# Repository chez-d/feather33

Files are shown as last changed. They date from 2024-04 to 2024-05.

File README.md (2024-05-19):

# feather33
Feather form-factor board with a 1.4GHz quad-core A33 from Allwinner.

For assembly, any <=512MB DDR3L should* work (no MCP). 

A 50p board-to-board connector is added to break out another USB, audio, and parallel RGB among other things

This board is designed to work with OSHPark's 6L service and to be assembled with a stencil and hotplate/hot air.

## Initial Testing
Assembled board works fine and communicates over USB.
2 IMPORTANT THINGS!!!
- You cannot boot from MMC1, sadly I discovered this *after* I got the boards. You'll have to first boot off of a SPI flash then use that to jump onto MMC1.
- DDR is still not confirmed.

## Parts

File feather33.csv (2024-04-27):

# | Reference | Qty | Value | Footprint | DNP
1 | C1, C3, C8, C9, C10, C11, C16, C21, C22, C31, C40, C49, C56, C57 | 14 | 1u | Capacitor_SMD:C_0402_1005Metric
2 | C2, C17, C20, C24, C25, C29, C30, C32, C33, C34, C35, C37, C42, C45, C46, C47, C50, C51, C52, C55, C60, C61, C62, C63, C64, C66, C67, C68, C69, C70 | 30 | 100n | Capacitor_SMD:C_0402_1005Metric
3 | C4, C5, C6, C7, C18, C19, C48, C65, C71 | 9 | 22u | Capacitor_SMD:C_0805_2012Metric
4 | C12, C13, C14, C15, C23, C28, C36, C41, C43, C44 | 10 | 10u | Capacitor_SMD:C_0603_1608Metric
5 | C26, C27, C38, C39 | 4 | TBD | Capacitor_SMD:C_0402_1005Metric
6 | CN1 | 1 | YXT-BB10-50P-02 | parts:CONN-SMD_YXT-BB10-50P-02
7 | D1 | 1 | STAT | LED_SMD:LED_0603_1608Metric
8 | D2, D3 | 2 | D_Schottky | Diode_SMD:D_SOD-323
9 | D4 | 1 | PWR | LED_SMD:LED_0603_1608Metric
10 | J1 | 1 | Micro_SD_Card_Det2 | Connector_Card:microSD_HC_Molex_104031-0811
11 | J2 | 1 | USB_C_Receptacle_USB2.0 | parts:USB-C_SMD-TYPE-C-31-M-12
12 | J3 | 1 | BATT | parts:CONN-SMD_X2016WRS-02-9TSW
13 | J4 | 1 | qwiic | Connector_JST:JST_SH_BM04B-SRSS-TB_1x04-1MP_P1.00mm_Vertical
14 | J5 | 1 | Conn_01x16 | parts:PinHeader_1x16_P2.54mm_Feather
15 | J6 | 1 | Conn_01x12 | parts:PinHeader_1x12_P2.54mm_Feather
16 | L1, L2, L3 | 3 | 1uH | parts:IND-SMD_L2.5-W2.0-VLS252012CX-150M
17 | R1 | 1 | 1k | Resistor_SMD:R_0402_1005Metric
18 | R2, R14, R19, R23, R24, R33 | 6 | 2k | Resistor_SMD:R_0402_1005Metric
19 | R3 | 1 | 124k | Resistor_SMD:R_0402_1005Metric
20 | R4, R12, R16 | 3 | 100k | Resistor_SMD:R_0402_1005Metric
21 | R5, R10, R13 | 3 | 10k | Resistor_SMD:R_0402_1005Metric
22 | R6, R15 | 2 | 68k | Resistor_SMD:R_0402_1005Metric
23 | R7 | 1 | 82k | Resistor_SMD:R_0402_1005Metric
24 | R8 | 1 | 510k | Resistor_SMD:R_0402_1005Metric
25 | R9 | 1 | 110k | Resistor_SMD:R_0402_1005Metric
26 | R11 | 1 | 316k | Resistor_SMD:R_0402_1005Metric
27 | R17, R18, R20, R21 | 4 | 5.1k | Resistor_SMD:R_0402_1005Metric
28 | R22 | 1 | 200k | Resistor_SMD:R_0402_1005Metric
29 | R25, R26 | 2 | 22 | Resistor_SMD:R_0402_1005Metric
30 | R27, R31 | 2 | 240 | Resistor_SMD:R_0402_1005Metric
31 | SW1 | 1 | SW_Push | Button_Switch_SMD:SW_SPST_PTS810
32 | U1 | 1 | BQ24040DSQR | parts:WSON-10_L2.0-W2.0-P0.40-BL-EP
33 | U2 | 1 | ~ | Package_DFN_QFN:VQFN-24-1EP_4x4mm_P0.5mm_EP2.5x2.5mm
34 | U3 | 1 | A33 | parts:BGA-282_L14.0-W14.0-R17-W17-P0.8-TL
35 | U5 | 1 | K4B4G1646E-BYMA 4GB | parts:FBGA-96_L13.5-W7.5-R16-C6-P0.80-TL
36 | U6 | 1 | NEOPIXEL | parts:LED-SMD_4P-L1.6-W1.5_XL-1615RGBC-WS2812B
37 | Y1 | 1 | 32768 | Crystal:Crystal_SMD_3215-2Pin_3.2x1.5mm
38 | Y2 | 1 | 24M | Crystal:Crystal_SMD_2016-4Pin_2.0x1.6mm

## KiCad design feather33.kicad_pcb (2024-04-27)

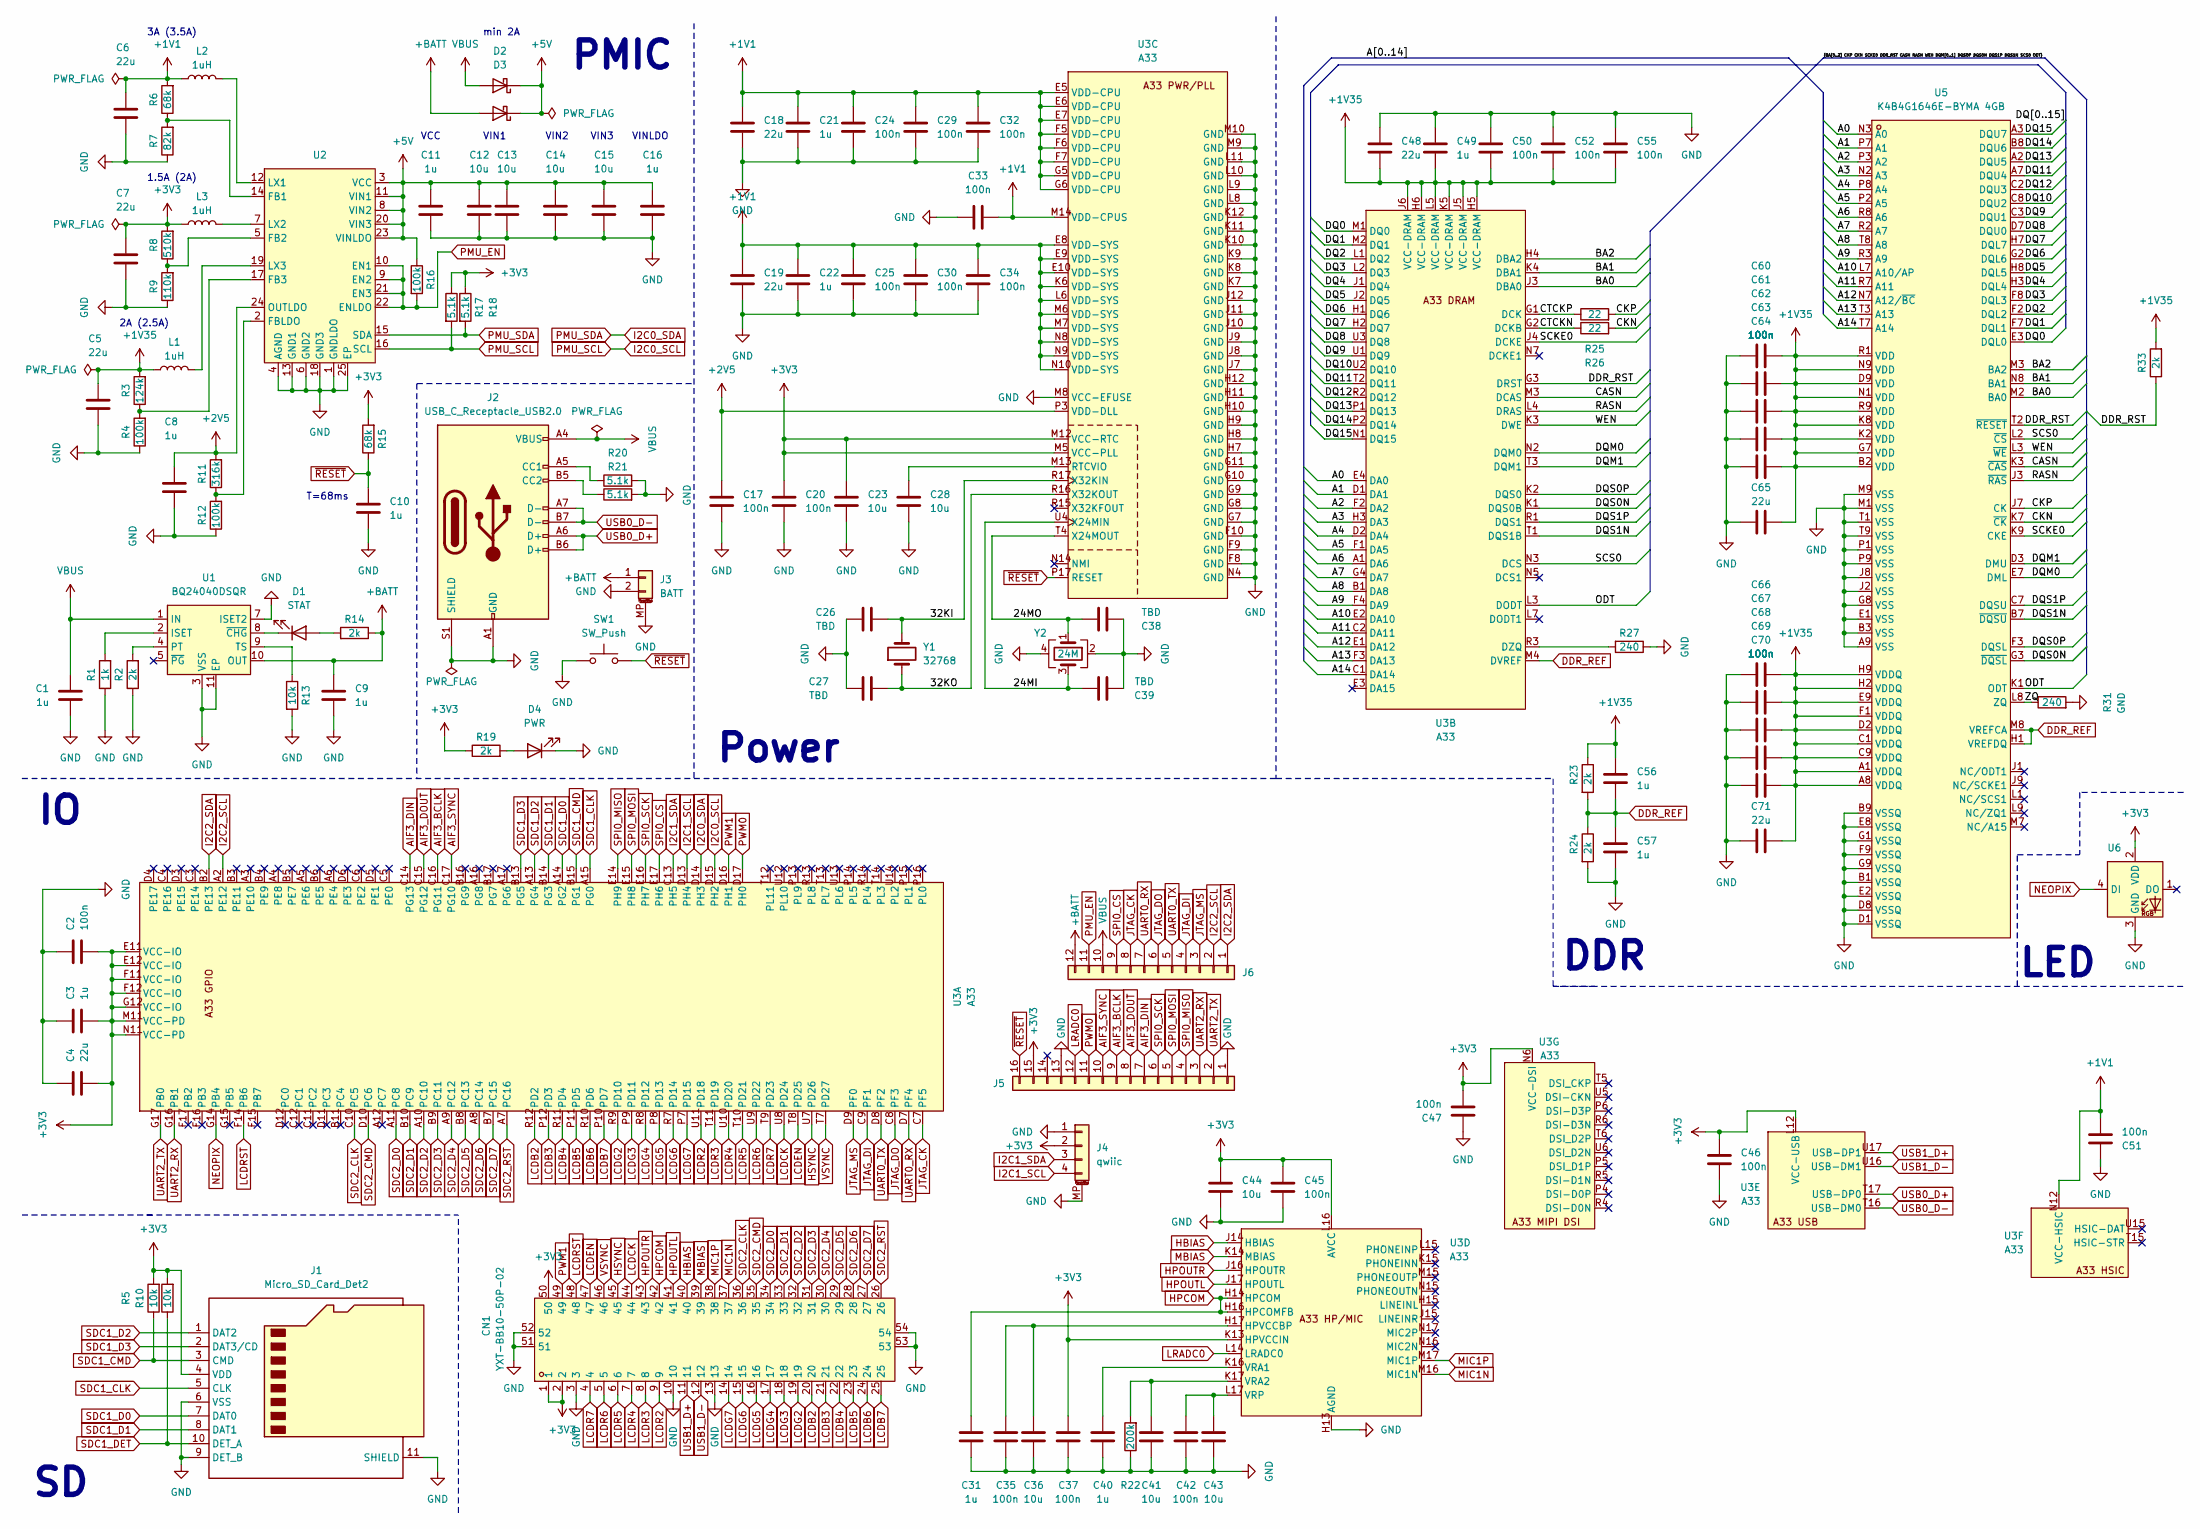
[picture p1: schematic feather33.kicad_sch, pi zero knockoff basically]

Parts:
C1, C3, C8, C9, C10, C11, C16, C21, C22, C31, C40, C49, C56, C57: 1u; C_0402_1005Metric
C2, C17, C20, C24, C25, C29, C30, C32, C33, C34, C35, C37, C42, C45, C46, C47, C50, C51, C52, C55, C60, C61, C62, C63, C64, C66, C67, C68, C69, C70: 100n; C_0402_1005Metric
C4, C5, C6, C7, C18, C19, C48, C65, C71: 22u; C_0805_2012Metric
C12, C13, C14, C15, C23, C28, C36, C41, C43, C44: 10u; C_0603_1608Metric
C26, C27, C38, C39: TBD; C_0402_1005Metric
CN1: YXT-BB10-50P-02; CONN-SMD_YXT-BB10-50P-02; LCSC Part C2763977
D1: STAT; LED_0603_1608Metric
D2, D3: D_Schottky; D_SOD-323
D4: PWR; LED_0603_1608Metric
J1: Micro_SD_Card_Det2; microSD_HC_Molex_104031-0811
J2: USB_C_Receptacle_USB2.0; USB-C_SMD-TYPE-C-31-M-12
J3: BATT; CONN-SMD_X2016WRS-02-9TSW
J4: qwiic; JST_SH_BM04B-SRSS-TB_1x04-1MP_P1.00mm_Vertical
J5: Conn_01x16; PinHeader_1x16_P2.54mm_Feather
J6: Conn_01x12; PinHeader_1x12_P2.54mm_Feather
L1, L2, L3: 1uH; IND-SMD_L2.5-W2.0-VLS252012CX-150M
R1: 1k; R_0402_1005Metric
R2, R14, R19, R23, R24, R33: 2k; R_0402_1005Metric
R3: 124k; R_0402_1005Metric
R4, R12, R16: 100k; R_0402_1005Metric
R5, R10, R13: 10k; R_0402_1005Metric
R6, R15: 68k; R_0402_1005Metric
R7: 82k; R_0402_1005Metric
R8: 510k; R_0402_1005Metric
R9: 110k; R_0402_1005Metric
R11: 316k; R_0402_1005Metric
R17, R18, R20, R21: 5.1k; R_0402_1005Metric
R22: 200k; R_0402_1005Metric
R25, R26: 22; R_0402_1005Metric
R27, R31: 240; R_0402_1005Metric
SW1: SW_Push; SW_SPST_PTS810
U1: BQ24040DSQR; WSON-10_L2.0-W2.0-P0.40-BL-EP; LCSC Part C81080
U2: VQFN-24-1EP_4x4mm_P0.5mm_EP2.5x2.5mm
U3: A33; BGA-282_L14.0-W14.0-R17-W17-P0.8-TL
U5: K4B4G1646E-BYMA 4GB; FBGA-96_L13.5-W7.5-R16-C6-P0.80-TL; LCSC Part C500275
U6: NEOPIXEL; LED-SMD_4P-L1.6-W1.5_XL-1615RGBC-WS2812B; LCSC Part C5349954
Y1: 32768; Crystal_SMD_3215-2Pin_3.2x1.5mm
Y2: 24M; Crystal_SMD_2016-4Pin_2.0x1.6mm

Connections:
+1V1: C6.1, C18.1, C19.1, C21.1, C22.1, C24.1, C25.1, C29.1, C30.1, C32.1, C33.2, C34.1, C51.2, L2.1, R6.2, U3.E5 (VDD-CPU), U3.E6 (VDD-CPU), U3.E7 (VDD-CPU), U3.E8 (VDD-SYS), U3.E9 (VDD-SYS), U3.E10 (VDD-SYS), U3.F5 (VDD-CPU), U3.F6 (VDD-CPU), U3.F7 (VDD-CPU), U3.G5 (VDD-CPU), U3.G6 (VDD-CPU), U3.K6 (VDD-SYS), U3.L6 (VDD-SYS), U3.M6 (VDD-SYS), U3.M7 (VDD-SYS), U3.M14 (VDD-CPUS), U3.N8 (VDD-SYS), U3.N9 (VDD-SYS), U3.N10 (VDD-SYS), U3.N12 (VCC-HSIC)
+1V35: C5.1, C48.2, C49.2, C50.2, C52.2, C55.2, C56.1, C60.2, C61.2, C62.2, C63.2, C64.2, C65.2, C66.2, C67.2, C68.2, C69.2, C70.2, C71.2, L1.1, R3.2, R23.1, R33.2, U3.H5 (VCC-DRAM), U3.H6 (VCC-DRAM), U3.J5 (VCC-DRAM), U3.J6 (VCC-DRAM), U3.K5 (VCC-DRAM), U3.L5 (VCC-DRAM), U5.A1 (VDDQ), U5.A8 (VDDQ), U5.B2 (VDD), U5.C1 (VDDQ), U5.C9 (VDDQ), U5.D2 (VDDQ), U5.D9 (VDD), U5.E9 (VDDQ), U5.F1 (VDDQ), U5.G7 (VDD), U5.H2 (VDDQ), U5.H9 (VDDQ), U5.K2 (VDD), U5.K8 (VDD), U5.N1 (VDD), U5.N9 (VDD), U5.R1 (VDD), U5.R9 (VDD)
+2V5: C8.1, C17.1, R11.2, U2.24 (OUTLDO), U3.P3 (VDD-DLL)
+3V3: C2.2, C3.2, C4.2, C7.1, C20.1, C23.1, C37.1, C44.1, C45.1, C46.1, C47.2, CN1.1, CN1.2, CN1.50, J1.4 (VDD), J4.2, J5.15, L3.1, R5.2, R8.2, R10.2, R15.2, R17.1, R18.1, R19.1, U3.E11 (VCC-IO), U3.E12 (VCC-IO), U3.F11 (VCC-IO), U3.F12 (VCC-IO), U3.G12 (VCC-IO), U3.K13 (HPVCCIN), U3.L12 (VCC-USB), U3.L16 (AVCC), U3.M5 (VCC-PLL), U3.M11 (VCC-PD), U3.M12 (VCC-RTC), U3.N6 (VCC-DSI), U3.N11 (VCC-PD), U6.2 (VDD)
+5V: C11.1, C12.1, C13.1, C14.1, C15.1, C16.1, D2.1 (K), D3.1 (K), R16.1, U2.3 (VCC), U2.8 (VIN2), U2.11 (VIN1), U2.20 (VIN3), U2.23 (VINLDO)
+BATT: C9.1, D3.2 (A), J3.1, J6.12, R14.1, U1.10 (OUT)
/24MI: C39.2, U3.U4 (X24MIN), Y2.3
/24MO: C38.2, U3.T4 (X24MOUT), Y2.1
/32KI: C26.2, U3.R17 (X32KIN), Y1.2
/32KO: C27.2, U3.R16 (X32KOUT), Y1.1
/A0: U3.E4 (DA0), U5.N3 (A0)
/A1: U3.D1 (DA1), U5.P7 (A1)
/A2: U3.F2 (DA2), U5.P3 (A2)
/A3: U3.H3 (DA3), U5.N2 (A3)
/A4: U3.D2 (DA4), U5.P8 (A4)
/A5: U3.F1 (DA5), U5.P2 (A5)
/A6: U3.A1 (DA6), U5.R8 (A6)
/A7: U3.G4 (DA7), U5.R2 (A7)
/A8: U3.B1 (DA8), U5.T8 (A8)
/A9: U3.F4 (DA9), U5.R3 (A9)
/A10: U3.E2 (DA10), U5.L7 (A10/AP)
/A11: U3.C2 (DA11), U5.R7 (A11)
/A12: U3.E1 (DA12), U5.N7 (A12/~BC)
/A13: U3.F3 (DA13), U5.T3 (A13)
/A14: U3.C1 (DA14), U5.T7 (A14)
/BA0: U3.J3 (DBA0), U5.M2 (BA0)
/BA1: U3.K4 (DBA1), U5.N8 (BA1)
/BA2: U3.H4 (DBA2), U5.M3 (BA2)
/CASN: U3.M3 (DCAS), U5.K3 (~CAS)
/CKN: R26.2, U5.K7 (~CK)
/CKP: R25.2, U5.J7 (CK)
/CTCKN: R26.1, U3.G2 (DCKB)
/CTCKP: R25.1, U3.G1 (DCK)
/DDR_RST: R33.1, U3.G3 (DRST), U5.T2 (~RESET)
/DQ0: U3.M1 (DQ0), U5.E3 (DQL0)
/DQ1: U3.M2 (DQ1), U5.F7 (DQL1)
/DQ2: U3.L1 (DQ2), U5.F2 (DQL2)
/DQ3: U3.L2 (DQ3), U5.F8 (DQL3)
/DQ4: U3.J1 (DQ4), U5.H3 (DQL4)
/DQ5: U3.J2 (DQ5), U5.H8 (DQL5)
/DQ6: U3.H1 (DQ6), U5.G2 (DQL6)
/DQ7: U3.H2 (DQ7), U5.H7 (DQL7)
/DQ8: U3.U3 (DQ8), U5.D7 (DQU0)
/DQ9: U3.U1 (DQ9), U5.C3 (DQU1)
/DQ10: U3.U2 (DQ10), U5.C8 (DQU2)
/DQ11: U3.T2 (DQ11), U5.A7 (DQU4)
/DQ12: U3.R2 (DQ12), U5.C2 (DQU3)
/DQ13: U3.P1 (DQ13), U5.A2 (DQU5)
/DQ14: U3.P2 (DQ14), U5.B8 (DQU6)
/DQ15: U3.N1 (DQ15), U5.A3 (DQU7)
/DQM0: U3.N2 (DQM0), U5.E7 (DML)
/DQM1: U3.T3 (DQM1), U5.D3 (DMU)
/DQS0N: U3.K1 (DQS0B), U5.G3 (~DQSL)
/DQS0P: U3.K2 (DQS0), U5.F3 (DQSL)
/DQS1N: U3.T1 (DQS1B), U5.B7 (~DQSU)
/DQS1P: U3.R1 (DQS1), U5.C7 (DQSU)
/ODT: U3.L3 (DODT), U5.K1 (ODT)
/RASN: U3.L4 (DRAS), U5.J3 (~RAS)
/SCKE0: U3.J4 (DCKE), U5.K9 (CKE)
/SCS0: U3.N3 (DCS), U5.L2 (~CS)
/WEN: U3.K3 (DWE), U5.L3 (~WE)
/ZQ: R31.1, U5.L8 (ZQ)
AIF3_BCLK: J5.9, U3.C16 (PG11)
AIF3_DIN: J5.7, U3.C14 (PG13)
AIF3_DOUT: J5.8, U3.C15 (PG12)
AIF3_SYNC: J5.10, U3.C17 (PG10)
DDR_REF: C56.2, C57.1, R23.2, R24.1, U3.M4 (DVREF), U5.H1 (VREFDQ), U5.M8 (VREFCA)
GND: C1.2, C2.1, C3.1, C4.1, C5.2, C6.2, C7.2, C8.2, C9.2, C10.2, C11.2, C12.2, C13.2, C14.2, C15.2, C16.2, C17.2, C18.2, C19.2, C20.2, C21.2, C22.2, C23.2, C24.2, C25.2, C26.1, C27.1, C28.2, C29.2, C30.2, C31.2, C32.2, C33.1, C34.2, C35.2, C36.2, C37.2, C38.1, C39.1, C40.2, C41.2, C42.2, C43.2, C44.2, C45.2, C46.2, C47.1, C48.1, C49.1, C50.1, C51.1, C52.1, C55.1, C57.2, C60.1, C61.1, C62.1, C63.1, C64.1, C65.1, C66.1, C67.1, C68.1, C69.1, C70.1, C71.1, CN1.3, CN1.10, CN1.13, CN1.51, CN1.52, CN1.53, CN1.54, D4.1 (K), J1.6 (VSS), J1.9 (DET_B), J1.11 (SHIELD), J2.A1 (GND), J2.A12 (GND), J2.B1 (GND), J2.B12 (GND), J2.S1 (SHIELD), J3.2, J3.MP (MountPin), J4.1, J4.MP (MountPin), J5.1, J5.13, R1.1, R2.1, R4.1, R7.1, R9.1, R12.1, R13.2, R20.2, R21.2, R22.1, R24.2, R27.1, R31.2, SW1.1, U1.3 (VSS), U1.7 (ISET2), U1.11 (EP), U2.1 (GNDLDO), U2.4 (AGND), U2.6 (GND2), U2.13 (GND1), U2.18 (GND3), U2.25 (EP), U3.F8 (GND), U3.F9 (GND), U3.F10 (GND), U3.G7 (GND), U3.G8 (GND), U3.G9 (GND), U3.G10 (GND), U3.G11 (GND), U3.H7 (GND), U3.H8 (GND), U3.H9 (GND), U3.H10 (GND), U3.H11 (GND), U3.H12 (GND), U3.H13 (AGND), U3.J7 (GND), U3.J8 (GND), U3.J9 (GND), U3.J10 (GND), U3.J11 (GND), U3.J12 (GND), U3.K7 (GND), U3.K8 (GND), U3.K9 (GND), U3.K10 (GND), U3.K11 (GND), U3.K12 (GND), U3.L8 (GND), U3.L9 (GND), U3.L10 (GND), U3.L11 (GND), U3.M8 (VCC-EFUSE), U3.M9 (GND), U3.M10 (GND), U3.N4 (GND), U5.A9 (VSS), U5.B1 (VSSQ), U5.B3 (VSS), U5.B9 (VSSQ), U5.D1 (VSSQ), U5.D8 (VSSQ), U5.E1 (VSS), U5.E2 (VSSQ), U5.E8 (VSSQ), U5.F9 (VSSQ), U5.G1 (VSSQ), U5.G8 (VSS), U5.G9 (VSSQ), U5.J2 (VSS), U5.J8 (VSS), U5.M1 (VSS), U5.M9 (VSS), U5.P1 (VSS), U5.P9 (VSS), U5.T1 (VSS), U5.T9 (VSS), U6.3 (GND), Y2.2, Y2.4
HBIAS: CN1.40, U3.J14 (HBIAS)
HPCOM: C31.1, CN1.42, U3.H14 (HPCOM), U3.H16 (HPCOMFB)
HPOUTL: CN1.41, U3.J17 (HPOUTL)
HPOUTR: CN1.43, U3.J16 (HPOUTR)
HSYNC: CN1.45, U3.U7 (PD26)
I2C0_SCL: R17.2, U2.16 (SCL), U3.D15 (PH2)
I2C0_SDA: R18.2, U2.15 (SDA), U3.D14 (PH3)
I2C1_SCL: J4.4, U3.D13 (PH4)
I2C1_SDA: J4.3, U3.C13 (PH5)
I2C2_SCL: J6.2, U3.A2 (PE12)
I2C2_SDA: J6.1, U3.B2 (PE13)
JTAG_CK: J6.8, U3.C7 (PF5)
JTAG_DI: J6.4, U3.C9 (PF1)
JTAG_DO: J6.6, U3.C8 (PF3)
JTAG_MS: J6.3, U3.D9 (PF0)
LCDB2: CN1.20, U3.R12 (PD2)
LCDB3: CN1.21, U3.P12 (PD3)
LCDB4: CN1.22, U3.R11 (PD4)
LCDB5: CN1.23, U3.P11 (PD5)
LCDB6: CN1.24, U3.R10 (PD6)
LCDB7: CN1.25, U3.P10 (PD7)
LCDCK: CN1.44, U3.U8 (PD24)
LCDEN: CN1.47, U3.T8 (PD25)
LCDG2: CN1.19, U3.R9 (PD10)
LCDG3: CN1.18, U3.P9 (PD11)
LCDG4: CN1.17, U3.R8 (PD12)
LCDG5: CN1.16, U3.P8 (PD13)
LCDG6: CN1.15, U3.R7 (PD14)
LCDG7: CN1.14, U3.P7 (PD15)
LCDR2: CN1.9, U3.U11 (PD18)
LCDR3: CN1.8, U3.T11 (PD19)
LCDR4: CN1.7, U3.U10 (PD20)
LCDR5: CN1.6, U3.T10 (PD21)
LCDR6: CN1.5, U3.U9 (PD22)
LCDR7: CN1.4, U3.T9 (PD23)
LCDRST: CN1.48, U3.F14 (PB6)
LRADC0: J5.12, U3.L14 (LRADC0)
MBIAS: CN1.39, U3.K14 (MBIAS)
MIC1N: CN1.37, U3.M16 (MIC1N)
MIC1P: CN1.38, U3.M17 (MIC1P)
NEOPIX: U3.G14 (PB4), U6.4 (DI)
unnamed: D1.2 (A), R14.2
unnamed: D1.1 (K), U1.8 (~CHG)
unnamed: D4.2 (A), R19.2
unnamed: J2.A5 (CC1), R20.1
unnamed: J2.B5 (CC2), R21.1
unnamed: R1.2, U1.2 (ISET)
unnamed: R2.2, U1.4 (PT)
unnamed: R13.1, U1.9 (TS)
unnamed: R6.1, R7.2, U2.14 (FB1)
unnamed: R8.1, R9.2, U2.5 (FB2)
unnamed: R3.1, R4.2, U2.17 (FB3)
unnamed: R11.1, R12.2, U2.2 (FBLDO)
unnamed: L2.2, U2.12 (LX1)
unnamed: L3.2, U2.7 (LX2)
unnamed: L1.2, U2.19 (LX3)
unnamed: R27.2, U3.R3 (DZQ)
unnamed: C28.1, U3.M13 (RTCVIO)
unnamed: C35.1, C36.1, U3.H17 (HPVCCBP)
unnamed: C40.1, U3.K16 (VRA1)
unnamed: C41.1, R22.2, U3.K17 (VRA2)
unnamed: C42.1, C43.1, U3.L17 (VRP)
PMU_EN: J6.11, R16.2, U2.9 (EN2), U2.10 (EN1), U2.21 (EN3), U2.22 (ENLDO)
PWM0: J5.11, U3.D17 (PH0)
PWM1: CN1.49, U3.D16 (PH1)
SDC1_CLK: J1.5 (CLK), U3.A15 (PG0)
SDC1_CMD: J1.3 (CMD), R5.1, U3.B15 (PG1)
SDC1_D0: J1.7 (DAT0), U3.A14 (PG2)
SDC1_D1: J1.8 (DAT1), U3.B14 (PG3)
SDC1_D2: J1.1 (DAT2), U3.A13 (PG4)
SDC1_D3: J1.2 (DAT3/CD), U3.B13 (PG5)
SDC1_DET: J1.10 (DET_A), R10.1
SDC2_CLK: CN1.36, U3.C10 (PC5)
SDC2_CMD: CN1.35, U3.D10 (PC6)
SDC2_D0: CN1.34, U3.A11 (PC8)
SDC2_D1: CN1.33, U3.B10 (PC9)
SDC2_D2: CN1.32, U3.A10 (PC10)
SDC2_D3: CN1.31, U3.B9 (PC11)
SDC2_D4: CN1.30, U3.A9 (PC12)
SDC2_D5: CN1.29, U3.B8 (PC13)
SDC2_D6: CN1.28, U3.A8 (PC14)
SDC2_D7: CN1.27, U3.B7 (PC15)
SDC2_RST: CN1.26, U3.A7 (PC16)
SPI0_CS: J6.9, U3.E17 (PH6)
SPI0_MISO: J5.4, U3.E14 (PH9)
SPI0_MOSI: J5.5, U3.E15 (PH8)
SPI0_SCK: J5.6, U3.E16 (PH7)
UART0_RX: J6.7, U3.D7 (PF4)
UART0_TX: J6.5, U3.D8 (PF2)
UART2_RX: J5.3, U3.G16 (PB1)
UART2_TX: J5.2, U3.G17 (PB0)
USB0_D+: J2.A6 (D+), J2.B6 (D+), U3.T17 (USB-DP0)
USB0_D-: J2.A7 (D-), J2.B7 (D-), U3.T16 (USB-DM0)
USB1_D+: CN1.11, U3.U17 (USB-DP1)
USB1_D-: CN1.12, U3.U16 (USB-DM1)
VBUS: C1.1, D2.2 (A), J2.A4 (VBUS), J2.A9 (VBUS), J2.B4 (VBUS), J2.B9 (VBUS), J6.10, U1.1 (IN)
VSYNC: CN1.46, U3.T7 (PD27)
~RESET: C10.1, J5.16, R15.1, SW1.2, U3.P17 (RESET)

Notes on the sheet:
min 2A
VIN1
T=68ms
PMIC
3A (3.5A)
1.5A (2A)
Power
DDR
2A (2.5A)
VIN2
VIN3
VINLDO
LED
VCC

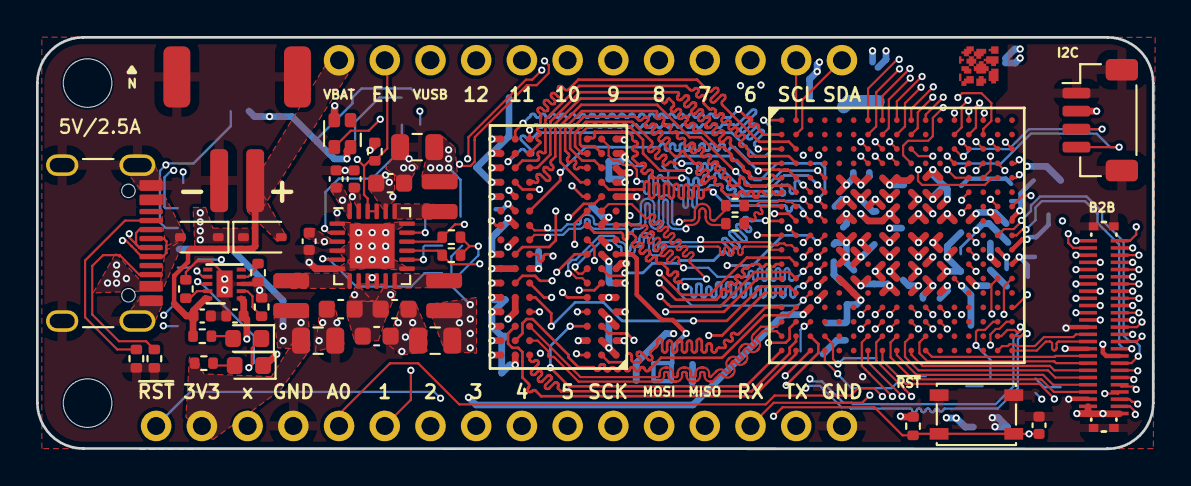
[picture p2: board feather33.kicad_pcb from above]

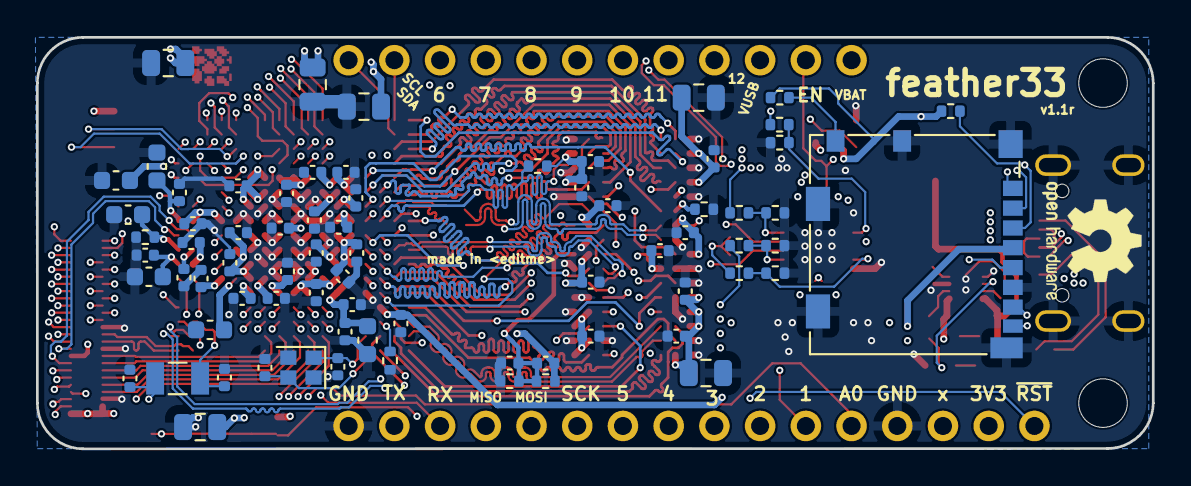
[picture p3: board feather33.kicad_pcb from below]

Board: 6 copper layers, 62.0 x 22.9 mm, 118 parts (73 on the bottom side), 166 nets.
